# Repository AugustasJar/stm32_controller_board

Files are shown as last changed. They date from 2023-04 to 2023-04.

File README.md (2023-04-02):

# stm32_controller_board
Board used for generic robotics control projects

The board uses an STM32F103C6B chip and it has various peripherals:

5-30V to 3.3V LDO,

pn-board L3GD20 gyroscope connected via SPI,

a mount for a NRF24L02 chip to be soldering directly on the board.

The board also has various IO:

Micro USB,

JTAG,

full pinout with screw terminals.

The board has to be programmed with a ST-LINK*



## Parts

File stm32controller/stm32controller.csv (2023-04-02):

Source: | C:\Users\augus\Documents\stm32controller\stm32controller.kicad_sch
Date: | 11/24/2022 8:51:36 AM
Tool: | Eeschema (6.0.9)
Generator: | C:\Program Files\KiCad\6.0\bin\scripting\plugins/bom_csv_grouped_by_value_with_fp.py
Component Count: | 41
Ref | Qnty | Value | Cmp name | Footprint | Description | Vendor
C1, C14, C15, | 3 | 100n | C | Capacitor_SMD:C_1206_3216Metric_Pad1.33x1.80mm_HandSolder | Unpolarized capacitor
C2, | 1 | 10u | C | Capacitor_SMD:C_0805_2012Metric_Pad1.18x1.45mm_HandSolder | Unpolarized capacitor
C3, C5, | 2 | 10p | C | Capacitor_SMD:C_0805_2012Metric_Pad1.18x1.45mm_HandSolder | Unpolarized capacitor
C4, C6, C7, C8, C9, C10, | 6 | 100n | C | Capacitor_SMD:C_0805_2012Metric_Pad1.18x1.45mm_HandSolder | Unpolarized capacitor
C11, | 1 | 1u | C | Capacitor_SMD:C_1206_3216Metric_Pad1.33x1.80mm_HandSolder | Unpolarized capacitor
C12, C13, C16, | 3 | 10u | C | Capacitor_SMD:C_1206_3216Metric_Pad1.33x1.80mm_HandSolder | Unpolarized capacitor
C17, | 1 | 10n | C | Capacitor_SMD:C_1206_3216Metric_Pad1.33x1.80mm_HandSolder | Unpolarized capacitor
D1, | 1 | LED | LED | LED_THT:LED_D4.0mm | Light emitting diode
H1, H2, H3, H4, | 4 | h | MountingHole_Pad | MountingHole:MountingHole_4mm_Pad_TopBottom | Mounting Hole with connection
J1, | 1 | 2x4 female connector | Conn_02x04_Odd_Even | Connector_PinHeader_2.54mm:PinHeader_2x04_P2.54mm_Vertical | Generic connector, double row, 02x04, odd/even pin numbering scheme (row 1 odd numbers, row 2 even numbers), script generated (kicad-library-utils/schlib/autogen/connector/)
J2, | 1 | USB_B_Micro | USB_B_Micro | Connector_USB:USB_Micro-B_Molex_47346-0001 | USB Micro Type B connector
J3, J4, J5, J6, J7, J8, J9, | 7 | 1x4 | Screw_Terminal_01x04 | TerminalBlock_Phoenix:TerminalBlock_Phoenix_MPT-0,5-4-2.54_1x04_P2.54mm_Horizontal | Generic screw terminal, single row, 01x04, script generated (kicad-library-utils/schlib/autogen/connector/)
J10, | 1 | Conn_02x05_Odd_Even | Conn_02x05_Odd_Even | Connector_Harwin:Harwin_M20-7810545_2x05_P2.54mm_Vertical | Generic connector, double row, 02x05, odd/even pin numbering scheme (row 1 odd numbers, row 2 even numbers), script generated (kicad-library-utils/schlib/autogen/connector/)
R1, | 1 | 10k | R | Resistor_SMD:R_1206_3216Metric_Pad1.30x1.75mm_HandSolder | Resistor
R5, R6, | 2 | 1k5 | R | Resistor_SMD:R_1206_3216Metric_Pad1.30x1.75mm_HandSolder | Resistor
SW1, | 1 | SW_SPST | SW_SPST | Button_Switch_THT:SW_TH_Tactile_Omron_B3F-10xx | Single Pole Single Throw (SPST) switch
SW2, | 1 | SW_SPDT | SW_SPDT | Button_Switch_SMD:SW_DPDT_CK_JS202011JCQN | Switch, single pole double throw
U1, | 1 | STM32F103CBT6 | STM32F103CBTx | Package_QFP:LQFP-48_7x7mm_P0.5mm | ARM Cortex-M3 MCU, 128KB flash, 20KB RAM, 72MHz, 2-3.6V, 37 GPIO, LQFP-48
U2, | 1 | AMS1117-3.3 | AMS1117-3.3 | Package_TO_SOT_SMD:SOT-223-3_TabPin2 | 1A Low Dropout regulator, positive, 3.3V fixed output, SOT-223
U3, | 1 | L3GD20 | L3GD20 | Package_LGA:LGA-16_4x4mm_P0.65mm_LayoutBorder4x4y | [Not recommended for new designs] 16-bit 3 Axis Digital MEMS Gyroscope, LGA-16
Y1, | 1 | 16MHz | Crystal_GND24 | Crystal:Crystal_SMD_TXC_7M-4Pin_3.2x2.5mm_HandSoldering | Four pin crystal, GND on pins 2 and 4

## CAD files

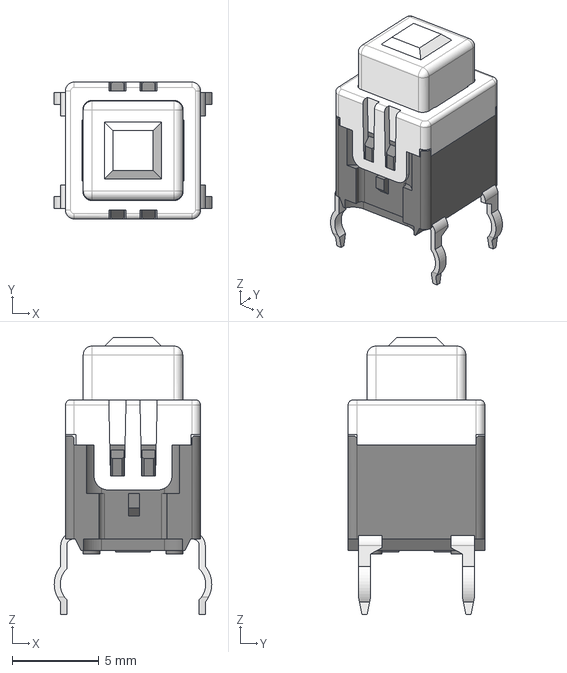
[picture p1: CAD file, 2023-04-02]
stm32controller/eec.models/Panasonic_-_ESE20C321.step
9.10 x 7.90 x 16.0 mm

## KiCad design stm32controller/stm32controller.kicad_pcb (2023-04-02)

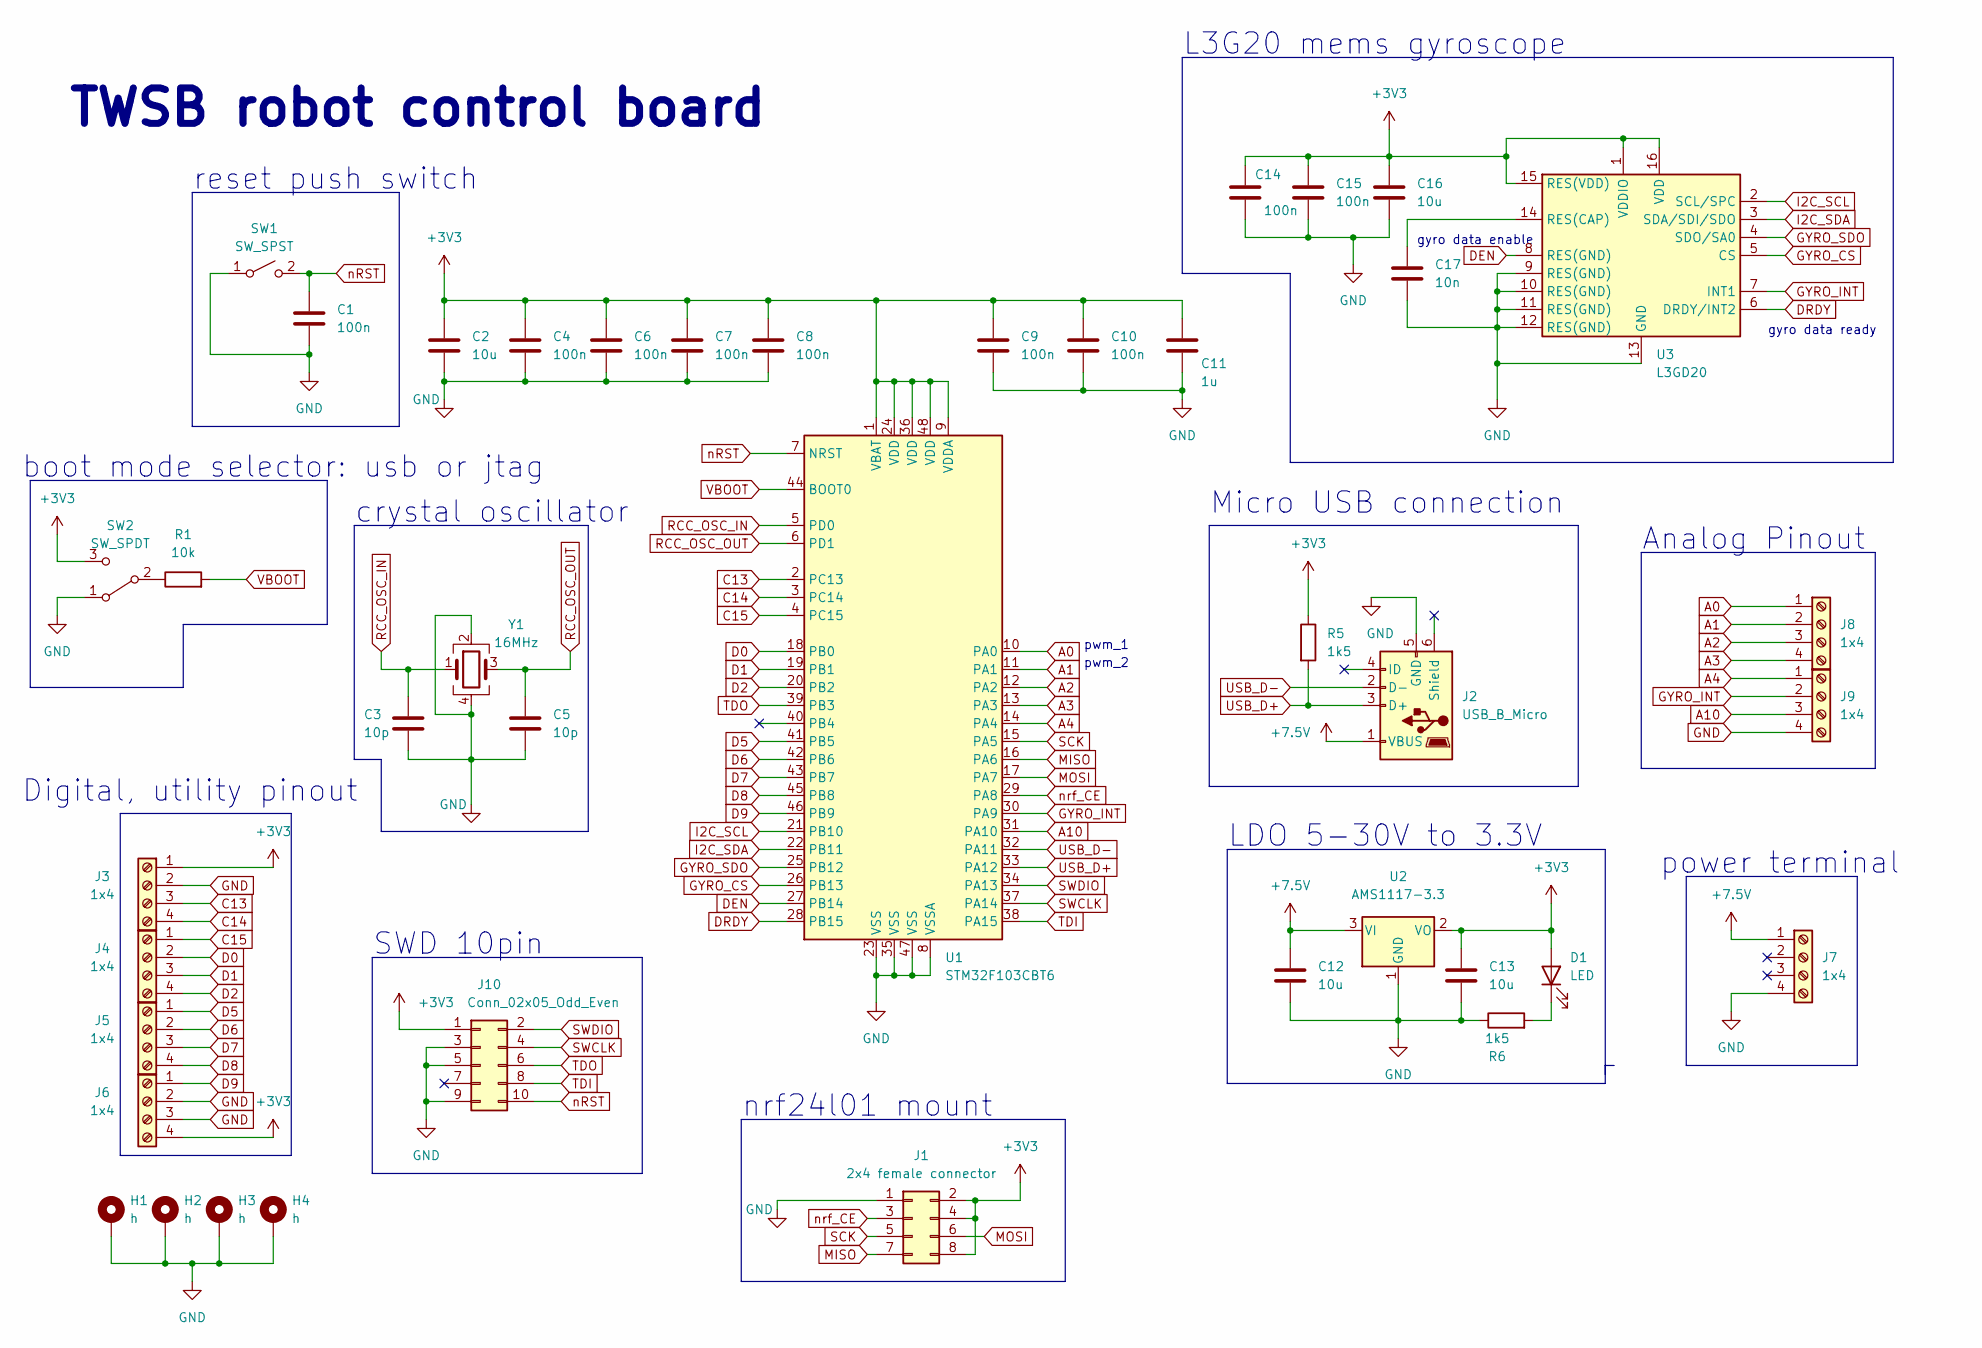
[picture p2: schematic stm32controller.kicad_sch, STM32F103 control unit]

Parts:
C1, C4, C6, C7, C8, C9, C10, C14, C15: 100n; C_0805_2012Metric_Pad1.18x1.45mm_HandSolder
C2, C12, C13, C16: 10u; C_1206_3216Metric_Pad1.33x1.80mm_HandSolder
C3, C5: 10p; C_1206_3216Metric_Pad1.33x1.80mm_HandSolder
C11: 1u; C_1206_3216Metric_Pad1.33x1.80mm_HandSolder
C17: 10n; C_1206_3216Metric_Pad1.33x1.80mm_HandSolder
D1: LED; LED_D4.0mm
H1, H2, H3, H4: h; MountingHole_4mm_Pad_TopBottom
J1: 2x4 female connector; PinHeader_2x04_P2.54mm_Vertical
J2: USB_B_Micro; USB_Micro-B_Molex_47346-0001
J3, J4, J5, J6, J7, J8, J9: 1x4; TerminalBlock_Phoenix_MPT-0,5-4-2.54_1x04_P2.54mm_Horizontal
J10: Conn_02x05_Odd_Even; PinHeader_2x05_P2.54mm_Vertical
R1: 10k; R_1206_3216Metric_Pad1.30x1.75mm_HandSolder
R5, R6: 1k5; R_1206_3216Metric_Pad1.30x1.75mm_HandSolder
SW1: SW_SPST; SW_TH_Tactile_Omron_B3F-10xx
SW2: SW_SPDT; SW_DPDT_CK_JS202011JCQN
U1: STM32F103CBT6; LQFP-48_7x7mm_P0.5mm
U2: AMS1117-3.3; SOT-223-3_TabPin2
U3: L3GD20; LGA-16_4x4mm_P0.65mm_LayoutBorder4x4y
Y1: 16MHz; Crystal_SMD_TXC_7M-4Pin_3.2x2.5mm_HandSoldering

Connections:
+3V3: C2.1, C4.1, C6.1, C7.1, C8.1, C9.1, C10.1, C11.1, C13.1, C14.1, C15.1, C16.1, D1.2 (A), J1.2, J1.4, J1.8, J3.1, J6.4, J10.1, R5.1, SW2.3 (C), U1.1 (VBAT), U1.9 (VDDA), U1.24 (VDD), U1.36 (VDD), U1.48 (VDD), U2.2 (VO), U3.1 (VDDIO), U3.15 (RES(VDD)), U3.16 (VDD)
+7.5V: C12.1, J2.1 (VBUS), J7.1, U2.3 (VI)
/RCC_OSC_IN: C3.1, U1.5 (PD0), Y1.1
/RCC_OSC_OUT: C5.1, U1.6 (PD1), Y1.3
/USB_D+: J2.3 (D+), R5.2, U1.33 (PA12)
/USB_D-: J2.2 (D-), U1.32 (PA11)
/variable_boot: R1.2, U1.44 (BOOT0)
A0: J8.1, U1.10 (PA0)
A1: J8.2, U1.11 (PA1)
A2: J8.3, U1.12 (PA2)
A3: J8.4, U1.13 (PA3)
A4: J9.1, U1.14 (PA4)
A10: J9.3, U1.31 (PA10)
C13: J3.3, U1.2 (PC13)
C14: J3.4, U1.3 (PC14)
C15: J4.1, U1.4 (PC15)
D0: J4.2, U1.18 (PB0)
D1: J4.3, U1.19 (PB1)
D2: J4.4, U1.20 (PB2)
D5: J5.1, U1.41 (PB5)
D6: J5.2, U1.42 (PB6)
D7: J5.3, U1.43 (PB7)
D8: J5.4, U1.45 (PB8)
D9: J6.1, U1.46 (PB9)
DEN: U1.27 (PB14), U3.8 (RES(GND))
DRDY: U1.28 (PB15), U3.6 (DRDY/INT2)
GND: C1.2, C2.2, C3.2, C4.2, C5.2, C6.2, C7.2, C8.2, C9.2, C10.2, C11.2, C12.2, C13.2, C14.2, C15.2, C16.2, C17.2, H1.1, H2.1, H3.1, H4.1, J1.1, J2.5 (GND), J3.2, J6.2, J6.3, J7.4, J9.4, J10.3, J10.5, J10.9, R6.1, SW1.1 (A), SW2.1 (A), U1.8 (VSSA), U1.23 (VSS), U1.35 (VSS), U1.47 (VSS), U2.1 (GND), U3.9 (RES(GND)), U3.10 (RES(GND)), U3.11 (RES(GND)), U3.12 (RES(GND)), U3.13 (GND), Y1.2, Y1.4
GYRO_CS: U1.26 (PB13), U3.5 (CS)
GYRO_INT: J9.2, U1.30 (PA9), U3.7 (INT1)
GYRO_SDO: U1.25 (PB12), U3.4 (SDO/SA0)
I2C_SCL: U1.21 (PB10), U3.2 (SCL/SPC)
I2C_SDA: U1.22 (PB11), U3.3 (SDA/SDI/SDO)
MISO: J1.7, U1.16 (PA6)
MOSI: J1.6, U1.17 (PA7)
unnamed: C17.1, U3.14 (RES(CAP))
unnamed: D1.1 (K), R6.2
unnamed: R1.1, SW2.2 (B)
SCK: J1.5, U1.15 (PA5)
SWCLK: J10.4, U1.37 (PA14)
SWDIO: J10.2, U1.34 (PA13)
TDI: J10.8, U1.38 (PA15)
TDO: J10.6, U1.39 (PB3)
nRST: C1.1, J10.10, SW1.2 (B), U1.7 (NRST)
nrf_CE: J1.3, U1.29 (PA8)

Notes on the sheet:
gyro data ready
Analog Pinout
pwm_2
nrf24l01 mount
pwm_1
SWD 10pin
gyro data enable
Micro USB connection
reset push switch
boot mode selector: usb or jtag
TWSB robot control board
LDO 5-30V to 3.3V
Digital, utility pinout
power terminal
L3G20 mems gyroscope
crystal oscillator

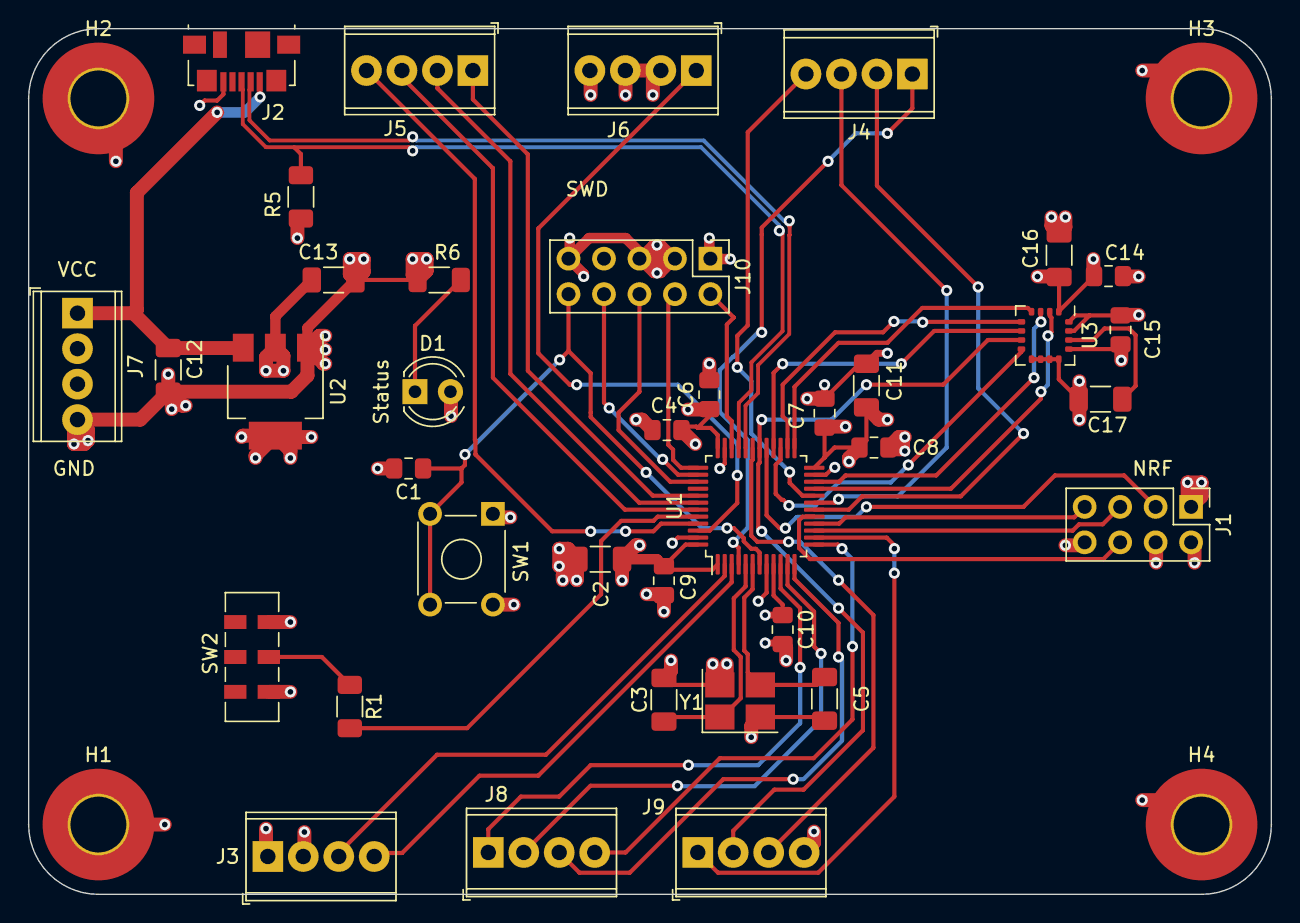
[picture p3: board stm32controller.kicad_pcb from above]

Board: 4 copper layers, 89.0 x 62.0 mm, 41 parts (0 on the bottom side), 44 nets.
